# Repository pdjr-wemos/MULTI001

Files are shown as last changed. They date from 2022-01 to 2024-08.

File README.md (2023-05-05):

# MULTI001
 
__MULTI001__ is an MQTT wireless sensor module based on the
[Wemos D1]().

The module can be connected to the following sensor devices and will
report readings from the connected devices over MQTT.

**AM2320** is connects to the I2C terminals and supplies temperature
and humidity readings.

**DS18B20** connects to the DS terminals and supplies temperature
readings.

**SmartDim** is a movement/occupancy sensor which can be connected
to the SDIM terminals and supplies lux and occupancy readings.

Additionally, up to four active-low SPST switches can be connected
to the CO, SW0, SW1, SW2 and SW3 terminals to provide switch state
readings.

BROWN  - +12VDC power-in\
YELLOW - GND\
ORANGE - PIR (normally 0VDC, 12VDC pulse when movement detected)\
YELLOW - LUX (0 - 12VDC representing LUX level)\
 
__MULTI001__ obtains temperature data from a DS18B20 digital thermometer.

## Installation

Connect the sensor module's power input terminals to a DC supply
voltage between 9VDC and 24VDC.

The module has an intermittent maximum power consumption of 500mW.

## Configuration

When powered for the first time __MULTI001__ launches a wireless access
point with an SSID of the form "MULTISENSOR-*mac-address*".
The access point implements a captive portal web-interface that allows
the user of a WiFi client to enter the following configuration parameters
that will subsequently be used by the sensor in normal operation:

* host network SSID (this can be selected from a scan list)
* host network password
* MQTT server hostname or IP address
* MQTT username, and
* MQTT password that will be used to authenticate publish requests
* MQTT sensor name (defaults to the device MAC address)

## Operation

After configuration, a power cycle on __MULT001__ will cause it to
reboot as a WiFi client on the host network specified during
configuration.
If the module cannot connect to the specified WiFi hotspot within two
minutes, then it will revert to configuration mode.

Once a connection to the host WiFi network is made the module will
immediately begin reporting sensor readings to the MQTT server using the
topic "multisensor/*sensor-name*/status".

The MQTT message payload is a JSON string of the form:

{\
  "temperature": *temperature*, // in degrees celsius\
  "motion": *yesno*, // 0 says no motion detected, 1 says motion detected\
  "lux": *percent* // 0..100 of the sensor range\
}\

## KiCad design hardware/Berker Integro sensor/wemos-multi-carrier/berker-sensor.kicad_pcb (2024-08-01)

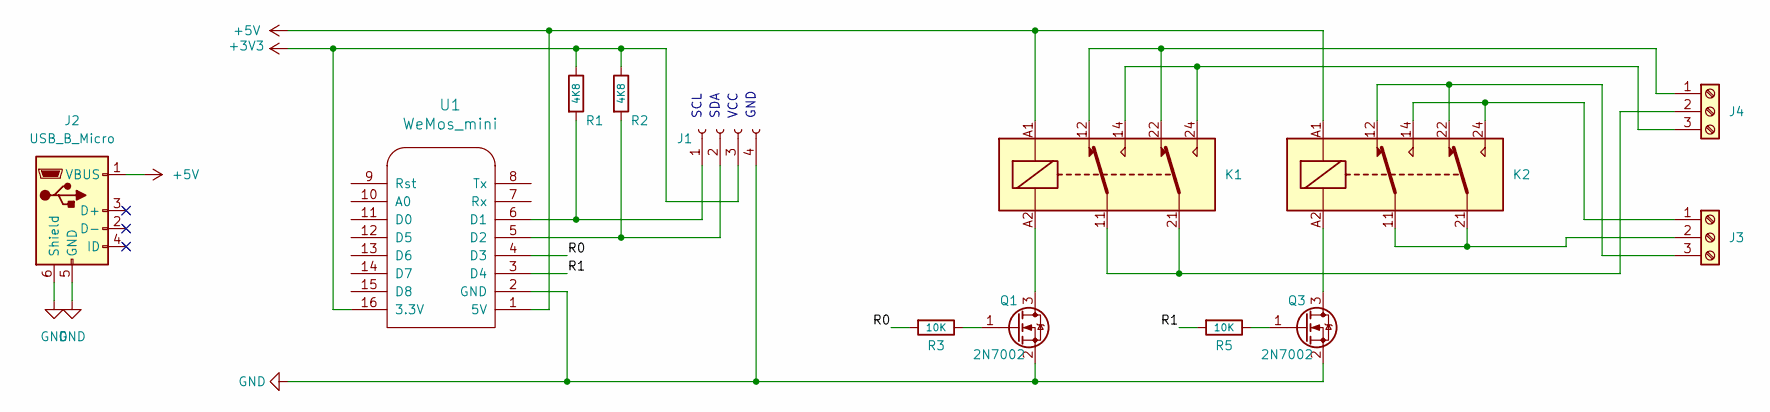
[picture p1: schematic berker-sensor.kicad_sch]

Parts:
J1: Conn_01x04_Socket; JST_GH_SM04B-GHS-TB_1x04-1MP_P1.25mm_Horizontal
J2: USB_B_Micro; USB_Micro-B_Wuerth_614105150721_Vertical
J3, J4: Screw_Terminal_01x03; RS_1731204_2.54x3_SCREW_TERMINAL
K1, K2: Relay_DPDT; RS_SUBMINIATURE_SIGNAL_RELAY
Q1, Q3: 2N7002; SOT-23
R1, R2: 4K8; R_0805_2012Metric
R3, R5: 10K; R_0805_2012Metric
U1: WeMos_mini; WEMOS_D1

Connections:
+3V3: J1.3, R1.1, R2.1, U1.16 (3.3V)
+5V: J2.1 (VBUS), K1.A1, K2.A1, U1.1 (5V)
/R0: R3.2, U1.4 (D3)
/R1: R5.2, U1.3 (D4)
GND: J1.4, J2.5 (GND), J2.6 (Shield), Q1.2 (S), Q3.2 (S), U1.2 (GND)
unnamed: J1.1, R1.2, U1.6 (D1)
unnamed: J1.2, R2.2, U1.5 (D2)
unnamed: J3.1, K2.14, K2.24
unnamed: J3.2, K2.11, K2.21
unnamed: J3.3, K2.12, K2.22
unnamed: J4.1, K1.12, K1.22
unnamed: J4.2, K1.11, K1.21
unnamed: J4.3, K1.14, K1.24
unnamed: K1.A2, Q1.3 (D)
unnamed: Q1.1 (G), R3.1
unnamed: K2.A2, Q3.3 (D)
unnamed: Q3.1 (G), R5.1

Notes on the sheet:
SCL
GND
VCC
SDA

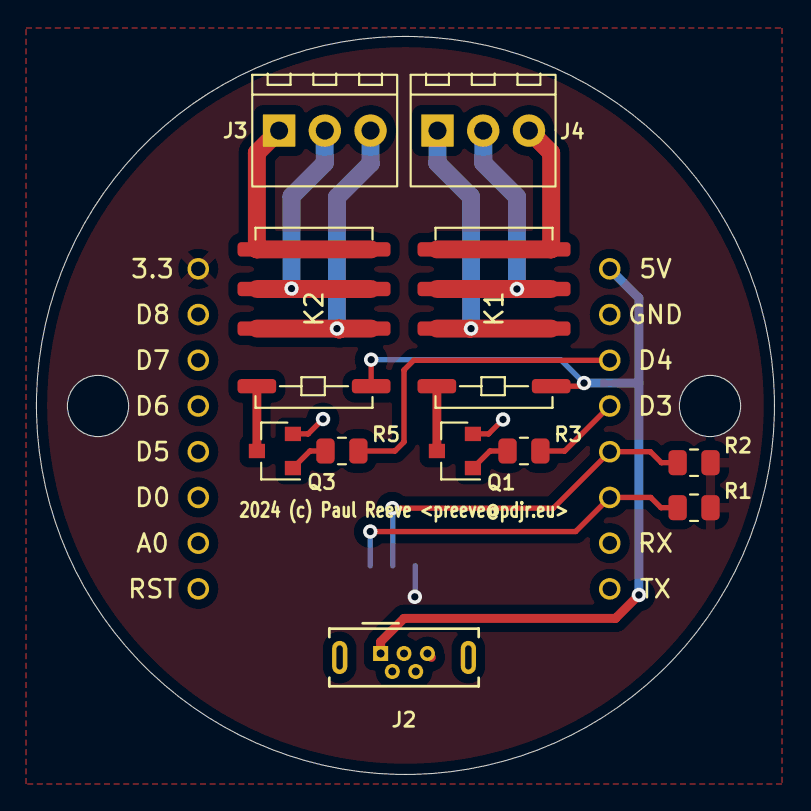
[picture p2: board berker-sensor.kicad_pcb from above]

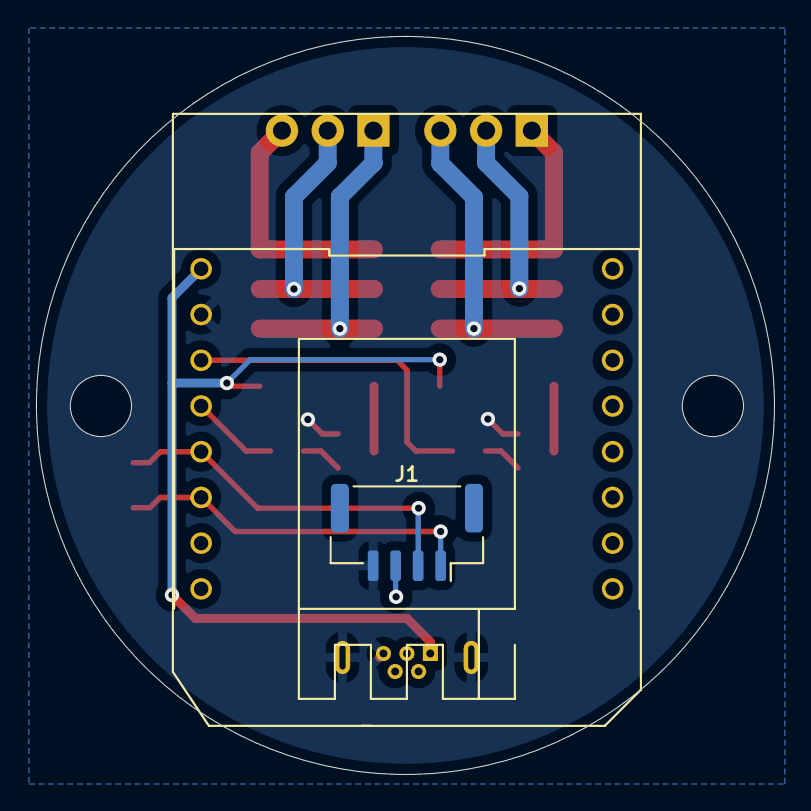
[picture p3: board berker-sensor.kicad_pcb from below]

Board: 2 copper layers, 41.0 x 41.0 mm, 13 parts (2 on the bottom side), 17 nets.

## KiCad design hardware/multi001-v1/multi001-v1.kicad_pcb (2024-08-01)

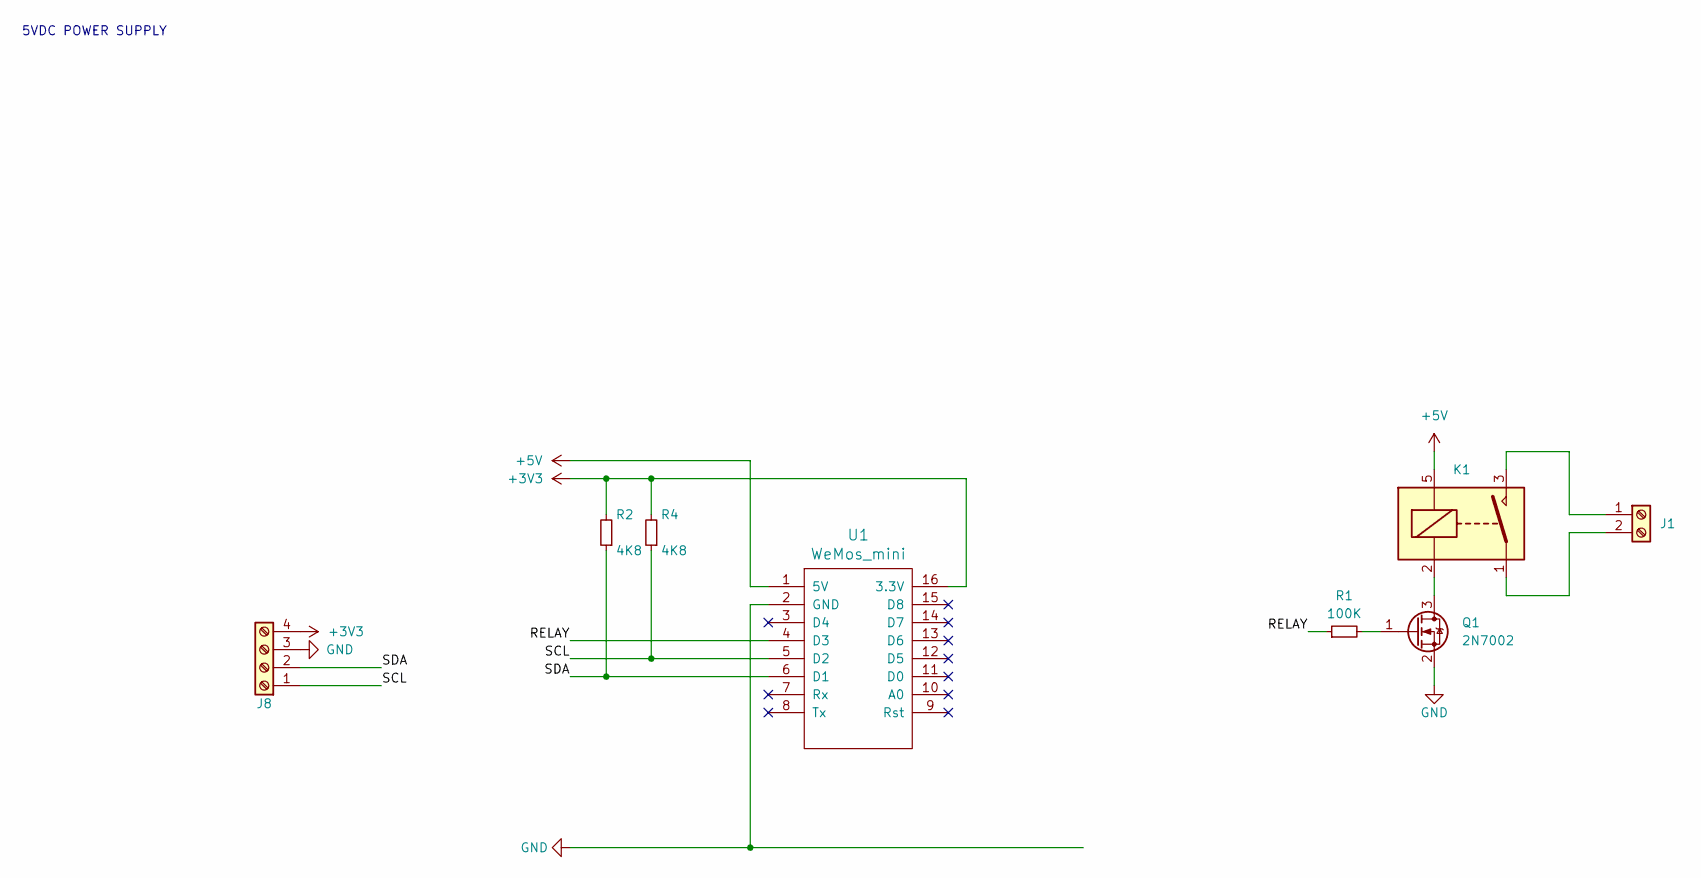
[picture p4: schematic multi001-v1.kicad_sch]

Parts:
J1: Screw_Terminal_01x02; PinHeader_1x02_P2.00mm_Vertical_SMD_Pin1Right
J8: Screw_Terminal_01x04; PinHeader_1x04_P2.54mm_Vertical
K1: SANYOU_SRD_Form_A; Relay_SPST_SANYOU_SRD_Series_Form_A
Q1: 2N7002; SOT-23
R1: 100K; R_0805_2012Metric
R2, R4: 4K8; R_0805_2012Metric
U1: WeMos_mini; D1_mini_board

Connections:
+3V3: J8.4, R2.2, R4.2, U1.16 (3.3V)
+5V: K1.5, U1.1 (5V)
/RELAY: R1.1, U1.4 (D3)
/SCL: J8.1, R4.1, U1.5 (D2)
/SDA: J8.2, R2.1, U1.6 (D1)
GND: J8.3, Q1.2 (S), U1.2 (GND)
unnamed 6: J1.1, K1.3; also elsewhere on the board
unnamed 7: J1.2, K1.1; also elsewhere on the board
unnamed: K1.2, Q1.3 (D)
unnamed: Q1.1 (G), R1.2

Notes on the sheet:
5VDC POWER SUPPLY

Board: 2 copper layers, 9 parts (0 on the bottom side), 10 nets, no tracks yet.

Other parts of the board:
J1#2: Screw_Terminal_01x02; PinHeader_1x02_P2.00mm_Vertical_SMD_Pin1Right

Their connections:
unnamed 6: J1#2.1; also elsewhere on the board
unnamed 7: J1#2.2; also elsewhere on the board

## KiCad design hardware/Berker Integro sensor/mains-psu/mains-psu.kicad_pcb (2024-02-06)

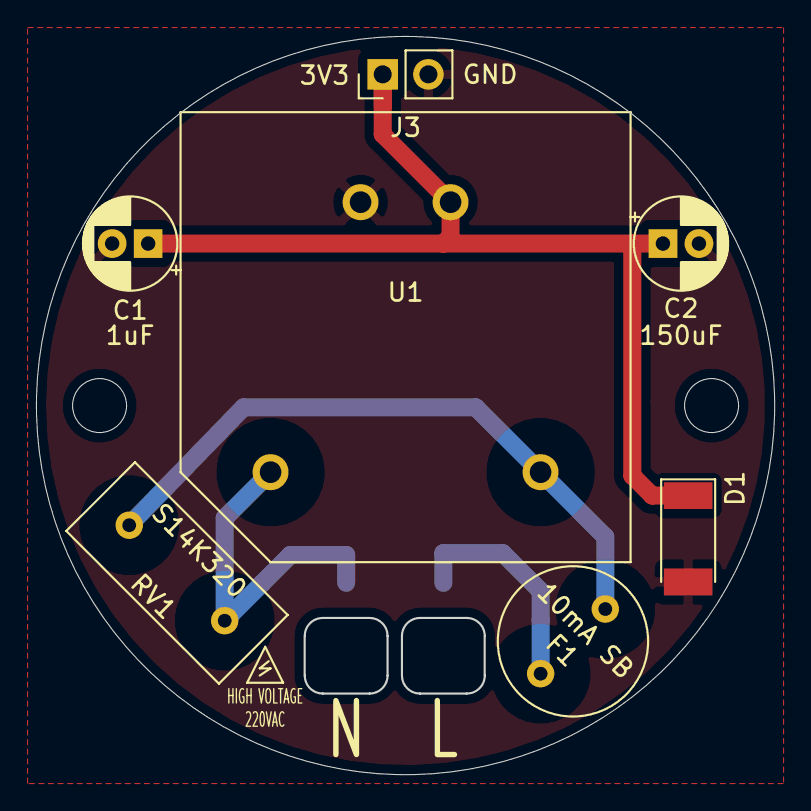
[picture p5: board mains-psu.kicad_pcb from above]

Board: 2 copper layers, 41.0 x 41.0 mm, 9 parts (0 on the bottom side), 5 nets.

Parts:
C1: 1uF; CP_Radial_D5.0mm_P2.00mm
C2: 150uF; CP_Radial_D5.0mm_P2.00mm
D1: D_Zener; D_MELF
F1: 10mA SB; BEL_MRT_SERIES
J1, J2: Conn_01x01; KYOCERA_POKEHOME_1P
J3: Conn_01x02; PinHeader_1x02_P2.54mm_Vertical
RV1: S14K320
U1: VTX-214-001-105; VTX-214-003-703

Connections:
+3V3: C1.1, C2.1, D1.1, J3.1, U1.3
GND: C1.2, C2.2, D1.2, J3.2, U1.4
LINE: F1.2, J1.1
NEUT: J2.1, RV1.2, U1.1
unnamed: F1.1, RV1.1, U1.2

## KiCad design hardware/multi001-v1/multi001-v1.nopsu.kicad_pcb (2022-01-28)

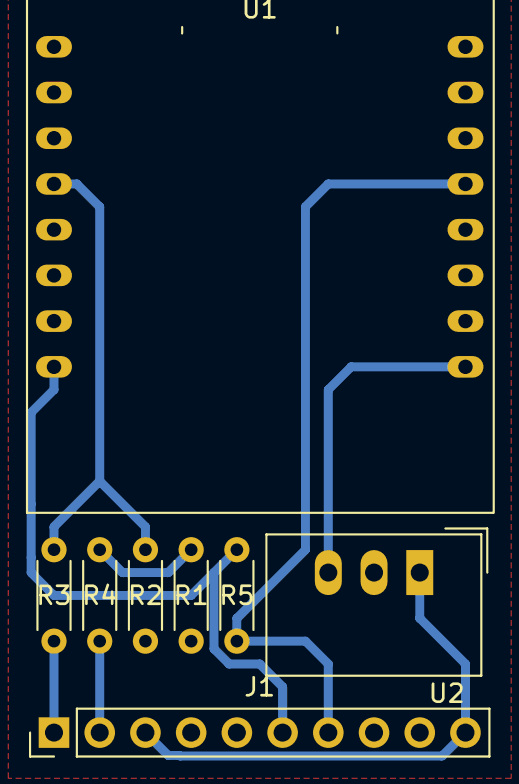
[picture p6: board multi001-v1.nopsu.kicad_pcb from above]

Board: 2 copper layers, 8 parts (0 on the bottom side), 9 nets.

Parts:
J1: Screw_Terminal_01x10; PinHeader_1x10_P2.54mm_Vertical
R1, R2: 3K2; R_Axial_DIN0204_L3.6mm_D1.6mm_P5.08mm_Horizontal
R3, R4: 9K1; R_Axial_DIN0204_L3.6mm_D1.6mm_P5.08mm_Horizontal
R5: 4K7; R_Axial_DIN0204_L3.6mm_D1.6mm_P5.08mm_Horizontal
U1: D1-MINI-V2; DIP-16_900_ELL
U2: OKI-78SR-5_1.5-W36-C; Converter_DCDC_TRACO_TSR-1_THT

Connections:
/LUX: R1.2, R4.1, U1.2
/PIR: R2.1, R3.1, U1.4
/TEMP: J1.7, R5.2, U1.13
GND: J1.4, J1.8, J1.9, R1.1, R2.2, U1.10, U2.2
unnamed: J1.1, R3.2
unnamed: J1.2, R4.2
unnamed: J1.6, R5.1, U1.8
unnamed: J1.3, J1.10, U2.1
unnamed: U1.9, U2.3

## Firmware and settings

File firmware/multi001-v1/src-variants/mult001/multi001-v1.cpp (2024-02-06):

/*********************************************************************
 * multi001-v1.cpp - multiple sensor wireless MQTT node.
 * 2021(c) Paul Reeve <preeve@pdjr.eu>
 * 
 * OVERVIEW
 * 
 * This firmware implements an IoT MQTT client which monitors
 * temperature, humidity and occupancy and publishes this
 * data as JSON formatted MQTT message of the form:
 * 
 *   '{ "temperature": t, "humidity": l, "motion": m }'
 * 
 * CONFIGURATION
 * 
 * The module automatically enters configuration mode when it is unable
 * to connect to an already configured WiFi host network or on first use
 * when no host network has been configured.
 * 
 * In configuration mode the module operates as a wireless access pointOn first use the
 * module must be configured by the user who is required to specify
 * the SSID and password of the hsensed data is
 * published to a user specified MQTT topic on a user defined MQTT
 * server accessed over a user-specfifiea JSON styled message of the form:
 * 
 *   '{ "temperature": t, "lux": l, "motion": m }'
 * 
 * to a user specified topic on a nominated MQTT server.
 * 
 * The code supports a DS18B20 temperature sensor reporting the sensed
 * value <t> in degrees centigrade.
 * 
 * Illumination (lux) level <l> (in the range 0..1023) and detected
 * motion <m> (as 0 or 1) are assumed to derive from a luxControl
 * SmartDim Sensor 2.
 * 
 * On first use (and also when the device is unable to connect to a
 * previously configured wireless network) the device will operate as
 * a wireless access point with the SSID "MULTISENSOR-xxxxxxxxxxxx",
 * where "xxxxxxxxxxxx" is the MAC address of the host wireless
 * interface.
 * 
 * Connecting to the access point will open a captured portal that
 * allows configuration of the following settings:
 * 
 * network - the SSID of the network to which the device should connect
 * password - any password required for connection to ssid
 * server name - the name or IP address of the target MQTT server
 * server port - the port on which the server listens (default 1886)
 * username - login user name required for access to the server
 * password - login password for username
 * topic - the topic on server to which sensor data should be published
 * 
 * Once the entered settings are saved the device will re-boot and
 * immediately attempt to report sensor readings to the configured
 * destination. Detected movement results in an immediate report, but
 * otherwise readings will be reported once every 60 seconds.
 */
 
#include <Arduino.h>
#include <ESP8266WiFi.h>
#include <PubSubClient.h>
#include <WiFiManager.h>
#include <EEPROM.h>
#include <OneWire.h>
#include <DallasTemperature.h>

#define DEBUG_SERIAL                      // Enable debug messages
#define DEBUG_SERIAL_START_DELAY 2000     // Milliseconds wait before output

#define GPIO_ONE_WIRE_BUS 4               // D1-MINI pin D2 (DS18B20 temp sensor)
#define GPIO_PIR_SENSOR 16                // D1-MINI pin D0
#define GPIO_SW0 14                       // D1-MINI pin D5
#define GPIO_SW1 12                       // D1-MINI pin D6
#define GPIO_SW2 13                       // D1-MINI pin D7
#define GPIO_SW3 15                       // D1-MINI pin D8
#define GPIO_LUX_SENSOR A0                // D1-MINI pin A0

#define MODULE_ID_FORMAT "MULTISENSOR-%02x%02x%02x%02x%02x%02x"
#define MQTT_DEFAULT_TOPIC_FORMAT "%s/status"

#define WIFI_SERVER_PORT 80               
#define WIFI_ACCESS_POINT_PORTAL_TIMEOUT 180 // In seconds

#define MQTT_PUBLISH_INTERVAL 30000
#define MQTT_CLIENT_ID "%02x%02x%02x%02x%02x%02x"
#define MQTT_STATUS_MESSAGE "{ \"temperature\": %f, \"motion\": %d, \"lux\": %d, \"sw0\": %d, \"sw1\": %d, \"sw2\": %d, \"sw3\": %d }" 

#define STORAGE_TEST_ADDRESS 0
#define STORAGE_TEST_VALUE 0xAE
#define MQTT_CONFIG_STORAGE_ADDRESS 1

#define LUX_FACTOR 2.7

/**********************************************************************
 * Structure to store MQTT configuration properties.
 */
struct MQTT_CONFIG { 
  char servername[40];  // MQTT server Hostname or IP address
  int  serverport;      // MQTT service port (normally 1883)
  char username[20];    // Name of user who can publish to the server
  char password[20];    // Password of named user
  char topic[60];       // MQTT topic on which to publish
};

#define TEMPERATURE_SENSOR_DETECT_TRIES 5
#define TEMPERATURE_SENSOR_I2C_ADDRESS 18

WiFiServer wifiServer(WIFI_SERVER_PORT);
WiFiClient wifiClient;
PubSubClient mqttClient(wifiClient);

OneWire oneWire(GPIO_ONE_WIRE_BUS);
DallasTemperature temperatureSensors(&oneWire);

/**********************************************************************
 * Setup a WiFi connection to <ssid>, <password> and only return once
 * a connection is established.
 */ 
void setup_wifi(const char* ssid, const char* password) {
  delay(10);
  WiFi.mode(WIFI_STA);
  WiFi.begin(ssid, password);  
  while (WiFi.status() != WL_CONNECTED) delay(500);
}

void connect_to_mqtt(const char* servername, const int serverport, const char* username, const char* password, const char* clientid) {
  while (!mqttClient.connected()) {
    #ifdef DEBUG_SERIAL
      Serial.print("Trying to connect to MQTT server ");
      Serial.print(servername); Serial.print(":"); Serial.print(serverport);
      Serial.print(" as ");
      Serial.print(username); Serial.print("("); Serial.print(password); Serial.print(")");
      Serial.print(" with client id ");
      Serial.println(clientid);
    #endif

    if (mqttClient.connect(clientid, username, password)) {
      #ifdef DEBUG_SERIAL
        Serial.println("connected");
      #endif
    } else {
      #ifdef DEBUG_SERIAL
        Serial.print("failed (result code = ");
        Serial.print(mqttClient.state());
        Serial.println("). Will try again in 5 seconds.");
      #endif
      delay(5000);
    }
  }
}

void dumpConfig(MQTT_CONFIG &config) {
  #ifdef DEBUG_SERIAL
  Serial.print("MQTT server name: "); Serial.println(config.servername);
  Serial.print("MQTT server port: "); Serial.println(config.serverport);
  Serial.print("MQTT username: "); Serial.println(config.username);
  Serial.print("MQTT password: "); Serial.println(config.password);
  Serial.print("MQTT topic: "); Serial.println(config.topic);
  #endif
}

boolean loadConfig(MQTT_CONFIG &config) {
  boolean retval = false;
  EEPROM.begin(512);
  if (EEPROM.read(0) == STORAGE_TEST_VALUE) {
    EEPROM.get(MQTT_CONFIG_STORAGE_ADDRESS, config);
    retval = true;
  }
  EEPROM.end();
  return(retval);
}

void saveConfig(MQTT_CONFIG &config) {
  #ifdef DEBUG_SERIAL
  Serial.println("Saving module configuration to EEPROM");
  dumpConfig(config);
  #endif
  EEPROM.begin(512);
  EEPROM.write(0, STORAGE_TEST_VALUE);
  EEPROM.put(MQTT_CONFIG_STORAGE_ADDRESS, config);
  EEPROM.commit();
  EEPROM.end();
}

bool shouldSaveConfig = false;

void saveConfigCallback() {
  shouldSaveConfig = true; 
}

byte macAddress[6];
char moduleId[40];
char defaultTopic[60];
MQTT_CONFIG mqttConfig;

float DETECTED_TEMPERATURE = 0.0; // Degrees Celsius
int DETECTED_MOTION = 0; // 0 = no motion detected, 1 = motion detected
int DETECTED_LUX = 0; // 0..1023
int DETECTED_SW0_STATE = 0;
int DETECTED_SW1_STATE = 0;
int DETECTED_SW2_STATE = 0;
int DETECTED_SW3_STATE = 0;

void setup() {
  #ifdef DEBUG_SERIAL
  Serial.begin(57600);
  delay(DEBUG_SERIAL_START_DELAY);
  #endif

  // Recover device MAC address and make from it a module identifier
  // that will be used as access point name, MQTT client id and a
  // component of the topic path (unless overriden by the user).
  WiFi.macAddress(macAddress);
  sprintf(moduleId, MODULE_ID_FORMAT, macAddress[0], macAddress[1], macAddress[2], macAddress[3], macAddress[4], macAddress[5]);
  sprintf(defaultTopic, MQTT_DEFAULT_TOPIC_FORMAT, moduleId);

  // Initialise the MQTT default configuration then try to load any saved data.
  // Create a WiFiManager instance and configure it.
  WiFiManager wifiManager;
  WiFiManagerParameter custom_mqtt_servername("server", "mqtt server", "", 40);
  WiFiManagerParameter custom_mqtt_serverport("port", "mqtt port", "1883", 6);
  WiFiManagerParameter custom_mqtt_username("user", "mqtt user", "", 20);
  WiFiManagerParameter custom_mqtt_password("pass", "mqtt pass", "", 20);
  WiFiManagerParameter custom_mqtt_topic("topic", "mqtt topic", defaultTopic, 40);
  
  // Try to load the module configuration.
  if (loadConfig(mqttConfig)) {
    // When the module WiFi service starts it may not be able to
    // connect to a wifi network and in this case will create an
    // access point to allow module configuration. We need to
    // create and initialise the WiFi manager configuration properties.
    WiFiManagerParameter custom_mqtt_servername("server", "mqtt server", mqttConfig.servername, 40);
    WiFiManagerParameter custom_mqtt_serverport("port", "mqtt port", "" + mqttConfig.serverport, 6);
    WiFiManagerParameter custom_mqtt_username("user", "mqtt user", mqttConfig.username, 20);
    WiFiManagerParameter custom_mqtt_password("pass", "mqtt pass", mqttConfig.password, 20);
    WiFiManagerParameter custom_mqtt_topic("topic", "mqtt topic", mqttConfig.topic, 40);
  } else {
    wifiManager.resetSettings();
  }  
  
  // Create a WiFiManager instance and configure it.
  wifiManager.setConfigPortalTimeout(WIFI_ACCESS_POINT_PORTAL_TIMEOUT);
  wifiManager.setSaveConfigCallback(saveConfigCallback);
  wifiManager.setBreakAfterConfig(true);
  wifiManager.addParameter(&custom_mqtt_servername);
  wifiManager.addParameter(&custom_mqtt_serverport);
  wifiManager.addParameter(&custom_mqtt_username);
  wifiManager.addParameter(&custom_mqtt_password);
  wifiManager.addParameter(&custom_mqtt_topic);
  
  // Finally, start the WiFi manager. 
  bool res = wifiManager.autoConnect(moduleId);

  // If the configuration data has changed, then get it and save it...
  if (shouldSaveConfig) {
    strcpy(mqttConfig.servername, custom_mqtt_servername.getValue());
    mqttConfig.serverport = atoi(custom_mqtt_serverport.getValue());
    strcpy(mqttConfig.username, custom_mqtt_username.getValue());
    strcpy(mqttConfig.password, custom_mqtt_password.getValue());
    strcpy(mqttConfig.topic, custom_mqtt_topic.getValue());
    saveConfig(mqttConfig);
  }

  // If we get to this point then the WiFi manager has either entered
  // configuration mode and being timed out or we are connected to the
  // configured network.  
  if (!res) {
    #ifdef DEBUG_SERIAL
      Serial.println("WiFi configuration or connection failure: restarting system.");
    #endif
    ESP.restart();
  } else {
    #ifdef DEBUG_SERIAL
      Serial.print("Connected to wireless network '");
      Serial.print(WiFi.SSID());
      Serial.println("'");
    #endif
    // We have a WiFi connection, so configure the MQTT connection
    mqttClient.setServer(mqttConfig.servername, mqttConfig.serverport);
    // Start sensing things
    temperatureSensors.begin();
    pinMode(GPIO_PIR_SENSOR, INPUT);
    pinMode(GPIO_SW0, INPUT_PULLUP);
    pinMode(GPIO_SW1, INPUT_PULLUP);
    pinMode(GPIO_SW2, INPUT_PULLUP);
    pinMode(GPIO_SW3, INPUT_PULLUP);
  }
}

/**********************************************************************
 * Check that we have an MQTT connection and if not, try and make one.
 * Otherwise, once every MQTT_PUBLISH_INTERVAL miliseconds read the
 * sensors and update the MQTT server.
 */
void loop() {
  static long mqttPublishDeadline = 0L;
  static char mqttStatusMessage[128];
  long now = millis();

  if (!mqttClient.connected()) connect_to_mqtt(mqttConfig.servername, mqttConfig.serverport, mqttConfig.username, mqttConfig.password, moduleId);
  mqttClient.loop();

  if ((DETECTED_MOTION) || (now > mqttPublishDeadline)) {
    // Recover temperature and lux sensor readings. There is no need to
    // explicitly recover the motion sensor reading because it is
    // maintained by an interrupt service routine. 
    temperatureSensors.requestTemperatures();
    DETECTED_TEMPERATURE = temperatureSensors.getTempCByIndex(0);
    DETECTED_MOTION = digitalRead(GPIO_PIR_SENSOR);
    DETECTED_SW0_STATE = digitalRead(GPIO_SW0);
    DETECTED_SW1_STATE = digitalRead(GPIO_SW1);
    DETECTED_SW2_STATE = digitalRead(GPIO_SW2);
    DETECTED_SW3_STATE = digitalRead(GPIO_SW3);
    DETECTED_LUX = (analogRead(GPIO_LUX_SENSOR) * LUX_FACTOR);
    DETECTED_LUX = (DETECTED_LUX > 1023)?1023:DETECTED_LUX;

    sprintf(mqttStatusMessage, MQTT_STATUS_MESSAGE, DETECTED_TEMPERATURE, DETECTED_MOTION, DETECTED_LUX, DETECTED_SW0_STATE, DETECTED_SW1_STATE, DETECTED_SW2_STATE, DETECTED_SW3_STATE);
    mqttClient.publish(mqttConfig.topic, mqttStatusMessage, true);

    mqttPublishDeadline = (now + MQTT_PUBLISH_INTERVAL);
    
    #ifdef DEBUG_SERIAL
      Serial.print("Writing ");
      Serial.print(mqttStatusMessage);
      Serial.print(" to ");
      Serial.println(mqttConfig.topic);
    #endif
  }
}

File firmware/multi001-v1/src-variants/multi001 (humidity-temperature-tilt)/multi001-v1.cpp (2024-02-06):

/*********************************************************************
 * NAME
 *   multi001-v1.cpp - multi-sensor wireless MQTT node.
 * PLATFORM
 *   ESP8266/Wemos MINI-D1
 * SENSORS
 *   AM2320 (I2C humidity and temperature)
 *   SPST switches (x4)
 * DESCRIPTION
 *   This firmware implements an IoT MQTT client which reports sensor
 *   data from SPST switches and a range of devices connected to the
 *   host microcontroller over I2C or one-wire busses.
 * 
 *   The generated MQTT message is a JSON object with properties
 *   reflecting data harvested from one or more of the following
 *   sensors.
 * 
 *   1. SPST switches
 *      Up to two active-low SPST switches can be connected to
 *      GPIO14(D5) and GPIO12(D6). The following two properties are
 *      always included in the output message (note that the reported
 *      property names can be overriden during module configuration).
 * 
 *      PROPERTY            VALUE
 *      sw0 (or alias)      Integer boolean 0 or 1 (OFF or ON) 
 *      sw1 (or alias)      Integer boolean 0 or 1 (OFF or ON)
* 
 *   2. AM2320 humidity & temperature
 *      
 *      A single sensor of this type can be connected to the I2C bus
 *      on GPIO5(D1/SCL) and GPIO4(D2/SDA). The sensor is automatically
 *      detected and no user configuration is required. Presence of the
 *      sensor adds the following properties to the output message.
 *      
 *      PROPERTY            VALUE
 *      humidity            Integer percent in the range 0..100
 *      temperature         Integer Celsius in the range -40..80
 * 
 *   3. DS18B20 temperature sensors
 * 
 *      An arbitrary number of sensors of this type can be connected to
 *      the one-wire bus on GPIO13(D?). Sensors are automatically
 *      detected and no user configuration is required. Each detected
 *      sensor adds a property of the following form to the output
 *      message.
 * 
 *      PROPERTY             VALUE
 *      DS-address           Integer Celsius in the range -40..120
 *  
 *   A JSON object containing properties relating to detected and/or
 *   configured sensors are published to a user defined topic on a user
 *   configured MQTT server (see CONFIGURATION below).
 * 
 *   The value 999, meaning undefined, is published to indicate that
 *   reading a detected or configured sensor failed for whatever reason.
 * 
 *   The defined MQTT topic is updated whenever a sensor value changes
 *   or once every 30 seconds. The maximum update rate is once every
 *   three seconds.
 * 
 * CONFIGURATION
 * 
 * On first use (and also when the device is unable to connect to a
 * previously configured wireless network) the device will operate as
 * an open wireless access point with the SSID "MULTISENSOR-xxxxxxxxxxxx",
 * where "xxxxxxxxxxxx" is the MAC address of the host wireless
 * interface.
 * 
 * Connection to this access point will open a captive portal that
 * allows the user to configure the following properties:
 * 
 * network                 The SSID of the host network to which the
 *                         device should connect.
 * 
 * password                The password (if any) required to connect to
 *                         specified host network.
 * 
 * server name             The name or IP address of the MQTT server to
 *                         which status updates should be sent.
 * 
 * server port             The port on which the server listens (default
 *                         1886).
 * 
 * username                The login user name required for access to
 *                         server name.
 * 
 * password                The login password for username.
 * 
 * topic                   The topic on which to publish data.
 * 
 * sw0 alias               A JSON property name to be used instead of
 *                         the default (sw0)
 *
 * sw1 alias               A JSON property name to be used instead of
 *                         the default (sw1)
 * 
 * When the configuration is saved the device will immediately reboot
 * and attempt to enter production with the specified configuration.
 */
 
#include <Arduino.h>
#include <ESP8266WiFi.h>
#include <PubSubClient.h>
#include <WiFiManager.h>
#include <EEPROM.h>
#include <Wire.h>
#include <AM232X.h>
#include <ArduinoJson.h>
#include <OneWire.h>
#include <DallasTemperature.h>

#define DEBUG_SERIAL                      // Enable debug messages
#define DEBUG_SERIAL_START_DELAY 2000     // Milliseconds wait before output

#define GPIO_SCL 5                        // I2C SCL
#define GPIO_SDA 4                        // I2C SDA
#define GPIO_ONE_WIRE_BUS 13              // For Dallas temperature sensors
#define GPIO_SW0 14                       // SPST switch
#define GPIO_SW1 12                       // SPST switch

#define MODULE_ID_FORMAT "MULTISENSOR-%02x%02x%02x%02x%02x%02x"

// User configuration access-point settings
#define AP_PORTAL_SERVICE_PORT 80               
#define AP_PORTAL_TIMEOUT 180

// User configuration property settings and defaults
#define CF_DEFAULT_MQTT_TOPIC_FORMAT "multisensor/%s"
#define CF_DEFAULT_MQTT_SERVICE_PORT 1886
#define CF_DEFAULT_PROPERTY_NAME_FOR_SW0 "sw0"
#define CF_DEFAULT_PROPERTY_NAME_FOR_SW1 "sw1"
#define CF_DEFAULT_MQTT_PUBLISH_SOFT_INTERVAL 3000
#define CF_DEFAULT_MQTT_PUBLISH_HARD_INTERVAL 30000

// Persistent storage addresses and default values
#define PS_IS_CONFIGURED_TOKEN_STORAGE_ADDRESS 0
#define PS_IS_CONFIGURED_TOKEN_VALUE 0xAE
#define PS_USER_CONFIGURATION_STORAGE_ADDRESS 1

// Miscellaneous sensor configuration settings 
#define AM2322_STARTUP_DELAY 2000
#define DS18B20_NAME_FORMAT "DS-%02x%02x%02x%02x%02x%02x%02x%02x"

#define JSON_BUFFER_SIZE 300
#define SENSOR_UNDEFINED_VALUE 999

/**********************************************************************
 * Structure to store user configuration. Note that the host network
 * settings are managed and persisted by the module itself.
 */
struct USER_CONFIGURATION { 
  char servername[40];            // MQTT server Hostname or IP address
  int  serverport;                // MQTT service port (normally 1883)
  char username[20];              // Name of user who can publish to the server
  char password[20];              // Password of named user
  char topic[60];                 // MQTT topic on which to publish
  int softpublicationinterval;    // Soft publication interval
  int hardpublicationinterval;    // Hard publication interval
  char sw0propertyname[20];       // Property name to use for first SPST switch
  char sw1propertyname[20];       // Property name to use for second SPST switch
};

/**********************************************************************
 * Globals representing WiFi and MQTT entities.
 */
WiFiServer wifiServer(AP_PORTAL_SERVICE_PORT);
WiFiClient wifiClient;
PubSubClient mqttClient(wifiClient);
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

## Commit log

2021-06-28 First upload
    [multi001-v1.kicad_pcb, multi001-v1.sch]
2022-01-28 New module type
    [multi001-nopir-v1.sch, multi001-v1.nopsu.kicad_pcb, multi001-v1.nopsu.sch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]
2023-05-06 Library fix
    [multi001-v1.sch]
2024-02-06 Enclosure tweak
    [berker-sensor-acdc.kicad_pcb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]
